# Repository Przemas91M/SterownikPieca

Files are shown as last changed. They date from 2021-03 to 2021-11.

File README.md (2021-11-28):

# Sterownik pompy pieca CO
Prosty sterownik pompy obiegowej pieca CO w oparciu o mikrokontroler ATmega328P-AU.  
Sterownik składa się z:
- czujnika temperatury DS18B20,
- wyświetlacza LCD 2x18,
- enkodera obrotowego dla zadawania nastaw temperatury,
- 2x przekaźniki do załączania pompy i buzzera ostrzegawczego.    
Sterownik załącza pompę, gdy temperatura wody w piecu osiągnie 30 st C.  
Powyżej 70 st C załącza się buzzer ostrzegawczy, aby nie zagotować wody w obiegu grzewczym.  
Gdy temperatura spadnie poniżej 30 st C, pompa jest wyłączana.

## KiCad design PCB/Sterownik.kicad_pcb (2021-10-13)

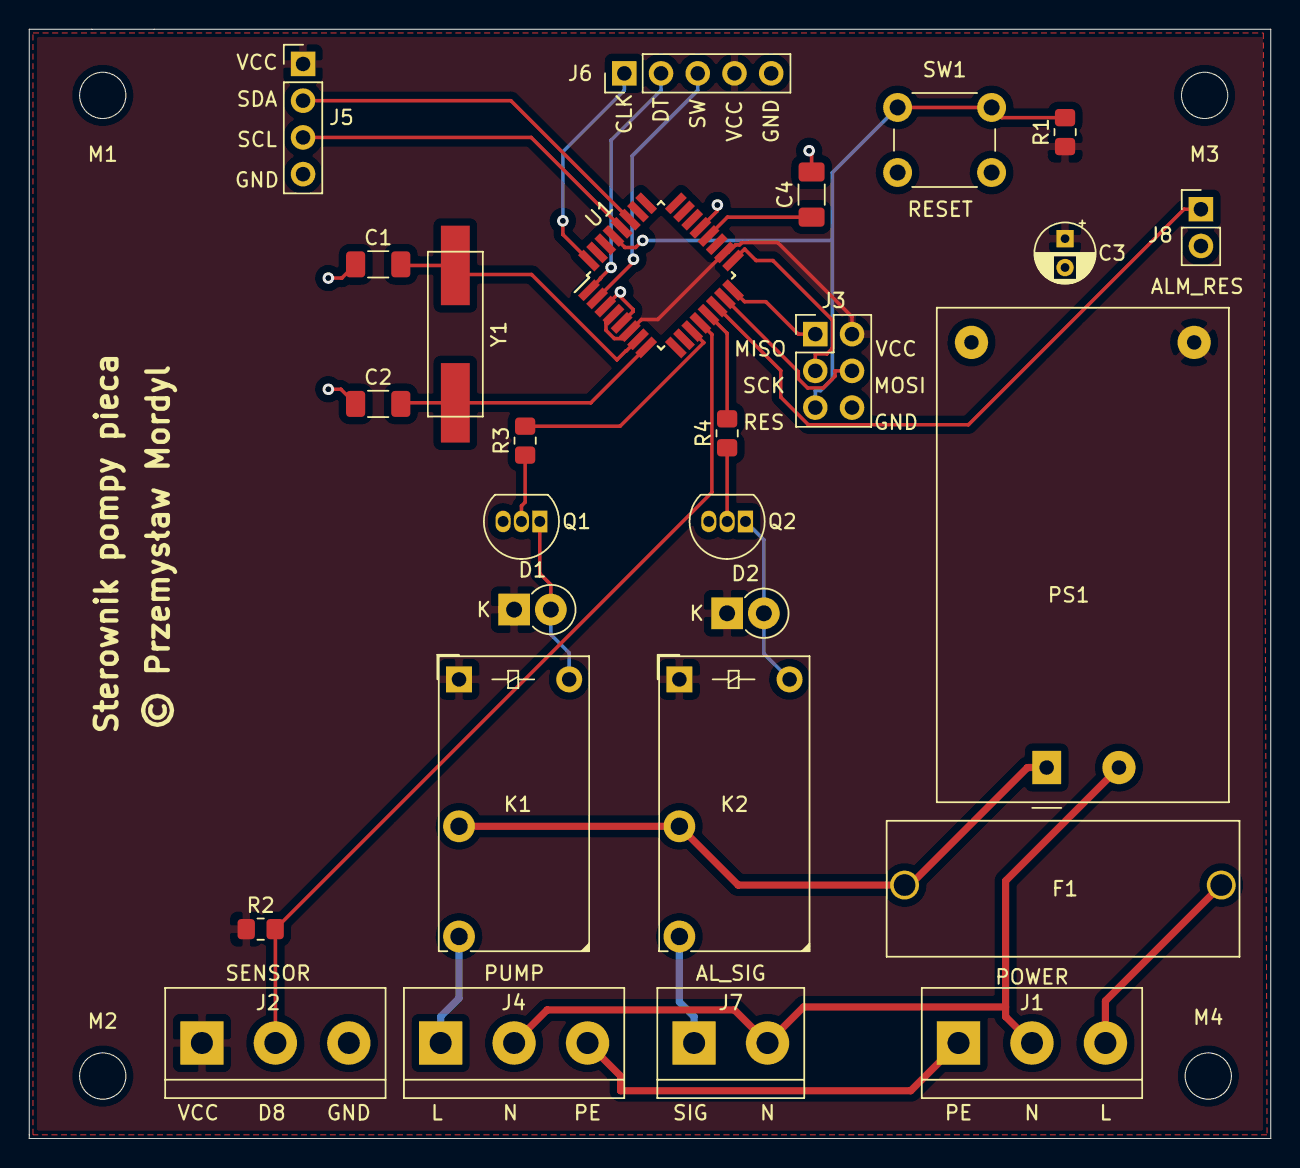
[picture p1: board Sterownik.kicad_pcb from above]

Board: 2 copper layers, 85.9 x 76.7 mm, 31 parts (0 on the bottom side), 28 nets.

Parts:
C1, C2: C; C_1206_3216Metric_Pad1.33x1.80mm_HandSolder
C3: 220uF; CP_Radial_D4.0mm_P2.00mm
C4: 100nF; C_1206_3216Metric_Pad1.33x1.80mm_HandSolder
D1, D2: 1N4007; D_DO-41_SOD81_P2.54mm_Vertical_KathodeUp
F1: 1A; FuseHolder PTF-78
J1: Zasilanie 230VAC; TerminalBlock_bornier-3_P5.08mm
J2: Złącze DS18B20; TerminalBlock_bornier-3_P5.08mm
J3: Conn_02x03_Odd_Even; PinHeader_2x03_P2.54mm_Vertical
J4: Złącze pompy; TerminalBlock_bornier-3_P5.08mm
J5: Wyświetlacz LCD; PinHeader_1x04_P2.54mm_Vertical
J6: Enkoder obrotowy; PinHeader_1x05_P2.54mm_Vertical
J7: Złącze brzęczyka; TerminalBlock_bornier-2_P5.08mm
J8: Złącze kasowania alarmu; PinHeader_1x02_P2.54mm_Vertical
K1: Załączenie pompy; Relay_SPST_Finder_32.21-x300
K2: Załączenie sygnalizatora alarmu; Relay_SPST_Finder_32.21-x300
M1, M2, M3, M4: MountingHole_3.2mm_M3_DIN965
PS1: HLK-PM01; Converter_ACDC_HiLink_HLK-PMxx
Q1, Q2: BC182; TO-92_Inline
R1: 10K; R_0805_2012Metric_Pad1.20x1.40mm_HandSolder
R2, R3, R4: 4,7K; R_0805_2012Metric_Pad1.20x1.40mm_HandSolder
SW1: SW_Push; SW_PUSH_6mm
U1: ATmega328P-AU; TQFP-32_7x7mm_P0.8mm
Y1: Crystal; Crystal_16MHz_SMD

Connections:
/L: F1.2, J1.3
/N: J1.2, J4.2, J7.2, PS1.2
/PE: J1.1, J4.3
A4: J5.2, U1.27
A5: J5.3, U1.28
D2: J6.1, U1.32
D3: J6.2, U1.1
D4: J6.3, U1.2
D7: R3.2, U1.11
D8: J2.2, R2.2, U1.12
D9: R4.2, U1.13
D10: J8.1, U1.14
D11\MOSI: J3.4, U1.15
D12\MISO: J3.1, U1.16
D13\SCK: J3.3, U1.17
GND: C1.1, C2.1, C3.2, C4.2, J2.3, J3.6, J5.4, J6.5, J8.2, PS1.3, Q1.3, Q2.3, SW1.1, U1.3, U1.5, U1.21
unnamed: C1.2, U1.7, Y1.1
unnamed: C2.2, U1.8, Y1.2
unnamed: C4.1, U1.20
unnamed: D1.2, K1.A2, Q1.1
unnamed: D2.2, K2.A2, Q2.1
unnamed: F1.1, K1.11, K2.11, PS1.1
unnamed: J4.1, K1.14
unnamed: J7.1, K2.14
unnamed: Q1.2, R3.1
unnamed: Q2.2, R4.1
RESET: J3.5, R1.2, SW1.2, U1.29
VCC: C3.1, D1.1, D2.1, J2.1, J3.2, J5.1, J6.4, K1.A1, K2.A1, PS1.4, R1.1, R2.1, U1.4, U1.6, U1.18

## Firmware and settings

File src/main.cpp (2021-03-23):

#include <Arduino.h>
#include <Wire.h>
#include <LiquidCrystal_I2C.h>
#include <OneWire.h>
#include <EEPROM.h>

#define relayPin 7  //D7
#define sensorPin 8 //D8
#define swPin 4     //D4
#define dtPin 2     //D2
#define clkPin 3    //D3

LiquidCrystal_I2C lcd(0x27, 16, 2);
OneWire ds(sensorPin);

byte data[12];
byte addr[8];
volatile int counter = 0;
bool aState, aLastState, swState, swState_old, reading;
float offTemp, warnTemp, offTemp_set, warnTemp_set, celsius;
int address = 0, menu = 0;
unsigned long now, waitRead, menuTimer;

//symbol termometru
byte termo[] =
    {
        B00100,
        B01010,
        B01010,
        B01010,
        B01110,
        B11111,
        B11111,
        B01110};

//symbol stopni
byte grade[] =
    {
        B11100,
        B10100,
        B11100,
        B00000,
        B00000,
        B00000,
        B00000,
        B00000};

//wyszukuje czujnik temperatury po adresach OneWire
void findSensor()
{
  ds.reset_search();
  while (!ds.search(addr))
  {
    //Serial.println("No more addresses.");
    //Serial.println();
    lcd.clear();
    lcd.setCursor(0, 0);
    lcd.print("Blad");
    lcd.setCursor(0, 1);
    lcd.print("czujnika");
    ds.reset_search();
    delay(250);
  }
  lcd.clear();
  lcd.setCursor(4, 0);
  lcd.print("Czujnik");
  lcd.setCursor(7, 1);
  lcd.print("OK");
  delay(2000);
}

//czyści wybraną linię w wyświetlaczu
void clearLine(int line)
{
  lcd.setCursor(0, line);
  for (int i = 0; i < 16; i++)
  {
    lcd.print(" ");
  }
}

//odczyt enkodera podczas przerwania i interpretacja kierunku obrotu
void readEncoder()
{
  aState = digitalRead(clkPin); // Reads the "current" state of the outputA
  // If the previous and the current state of the outputA are different, that means a Pulse has occured
  if (aState != aLastState)
  {
    // If the outputB state is different to the outputA state, that means the encoder is rotating clockwise
    if (digitalRead(dtPin) != aState)
    {
      counter++;
    }
    else
    {
      counter--;
    }
    //Serial.print("Position: ");
    //Serial.println(counter);
  }
  aLastState = aState; // Updates the previous state of the outputA with the current state
}

//zapisuje nowa wartosc temperatury wylaczenia pompy do pamieci
void updateOffTemp(float temp)
{
  if (temp != offTemp)
  {
    EEPROM.put(0, temp);
  }
}

//zapisuje nowa wartosc temperatury ostrzegania do pamieci
void updateWarnTemp(float temp)
{
  int addres = 0;
  addres += sizeof(float);
  if (temp != warnTemp)
  {
    EEPROM.put(addres, temp);
  }
}

void readTemperature()
{
  if (!reading)
  {
    ds.reset();
    ds.select(addr);
    ds.write(0x44, 1); // start conversion, with parasite power on at the end
    reading = true;
    waitRead = now;
    return;
  }

  if ((now - waitRead) > 1000)
  {
    // we might do a ds.depower() here, but the reset will take care of it.
    ds.reset();
    ds.select(addr);
    ds.write(0xBE); // Read Scratchpad
    for (byte i = 0; i < 9; i++)
    { // we need 9 bytes
      data[i] = ds.read();
    }
    // Convert the data to actual temperature
    // because the result is a 16 bit signed integer, it should
    // be stored to an "int16_t" type, which is always 16 bits
    // even when compiled on a 32 bit processor.
    int16_t raw = (data[1] << 8) | data[0];
    celsius = (float)raw / 16.0;
    reading = false;
  }
}

void setup()
{
  // put your setup code here, to run once:
  pinMode(dtPin, INPUT);
  pinMode(clkPin, INPUT);
  pinMode(swPin, INPUT);
  attachInterrupt(dtPin, readEncoder, CHANGE);
  attachInterrupt(clkPin, readEncoder, CHANGE);
  EEPROM.get(address, offTemp);
  address += sizeof(short);
  EEPROM.get(address, warnTemp);
  lcd.init();
  lcd.begin(16, 2);
  lcd.createChar(0, termo);
  lcd.createChar(1, grade);
  lcd.backlight();
  lcd.setCursor(4, 0);
  lcd.print("Hello");
  delay(2000);
  findSensor();
  lcd.clear();
  lcd.setCursor(0, 0);
  lcd.print(offTemp);
  lcd.setCursor(0, 1);
  lcd.print(warnTemp);
  delay(2000);
  lcd.clear();
  lcd.print("Temperatura:");
  //tylko w przypadku nowej płytki!!
  //EEPROM.put(address, offTemp);
  //address += sizeof(short);
  //EEPROM.put(address, warnTemp);
  Serial.begin(9600);
}

void loop(void)
{
  now = millis();
  swState = digitalRead(swPin); //odczyt stanu przycisku
  if (swState != swState_old)   //sprawdzam wcisniecie przycisku (pominie, jezeli przycisk jest juz wcisniety)
  {
    swState_old = swState; //zapisuje wcisniecie, zeby non stop nie wykonywalo rozkazu
    if (swState)           //wywola sie w przypadku wcisniecia przycisku
    {
      menu++;
      menuTimer = now;
    }
  }
  readTemperature();
  //jezeli zostal przekrecony potencjometr
  if (menu == 0) //jestesmy w trybie wyswietlania temperatury
  {
    lcd.setCursor(0, 1);
    lcd.write(0);
    lcd.setCursor(3, 1);
    lcd.print(celsius);
    lcd.write(1);
    lcd.print("C");
    counter = 0;     //nic nie robimy, czekamy na wcisniecie przycisku
    lcd.backlight(); //odpalam podswietlenie
  }
  else if (menu == 1) //ustawienia temperatury wylaczenia
  {
    offTemp += (float)(counter * 0.5);
    lcd.setCursor(0, 0);
    lcd.print("Temp off:");
    lcd.setCursor(0, 1);
    lcd.print(offTemp);
    counter = 0;
  }
  else if (menu == 2)
  {
    warnTemp += (float)(counter * 0.5);
    lcd.setCursor(0, 0);
    lcd.print("Temp warn:");
    lcd.setCursor(0, 1);
    lcd.print(warnTemp);
    counter = 0;
  }
  else if(menu > 2)
  {
      updateWarnTemp(warnTemp);
      updateOffTemp(offTemp);
      menu = 0;
  }
Serial.println(menu);
Serial.println(swState);
delay(250);
  //Serial.print("  Temperature = ");
  //Serial.print(celsius);
  //Serial.print(" Celsius, ");
  //clearLine(1);
}

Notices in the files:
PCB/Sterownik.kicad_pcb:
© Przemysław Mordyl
